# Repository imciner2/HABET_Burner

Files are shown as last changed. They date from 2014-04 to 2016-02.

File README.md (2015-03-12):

HABET_Burner
============

Burner designed for High Altitude Ballooning

Housekeeping
============
This repository makes use of git subtrees for importing its KiCad libraries. Use the following commands to work with them
* To add the remote link: git remote add libraries https://github.com/imciner2/KiCad-Libraries.git
* To pull the newest version: git subtree pull --prefix Electronics/2-Hardware/2-DesignFiles/libraries libraries master --squash
* To push the changes to the repo: git subtree push --prefix Electronics/2-Hardware/2-DesignFiles/libraries libraries master

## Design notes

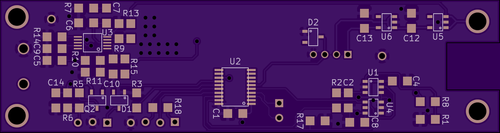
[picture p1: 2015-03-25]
Electronics/6-Documentation/Board_Bottom.png

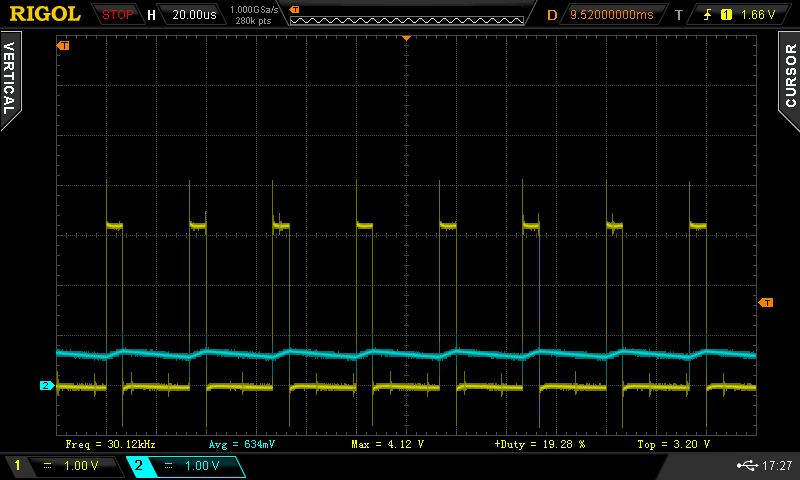
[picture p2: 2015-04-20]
Electronics/6-Documentation/PWM_Input_20Duty.png

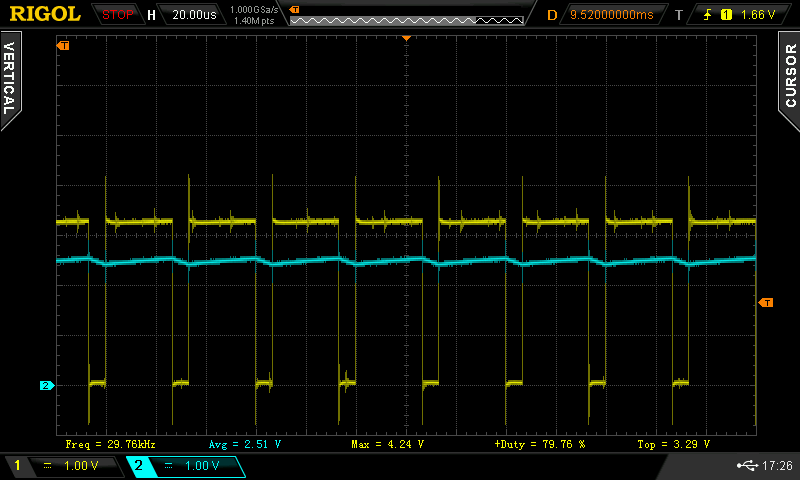
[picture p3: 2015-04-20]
Electronics/6-Documentation/PWM_Input_80Duty.png

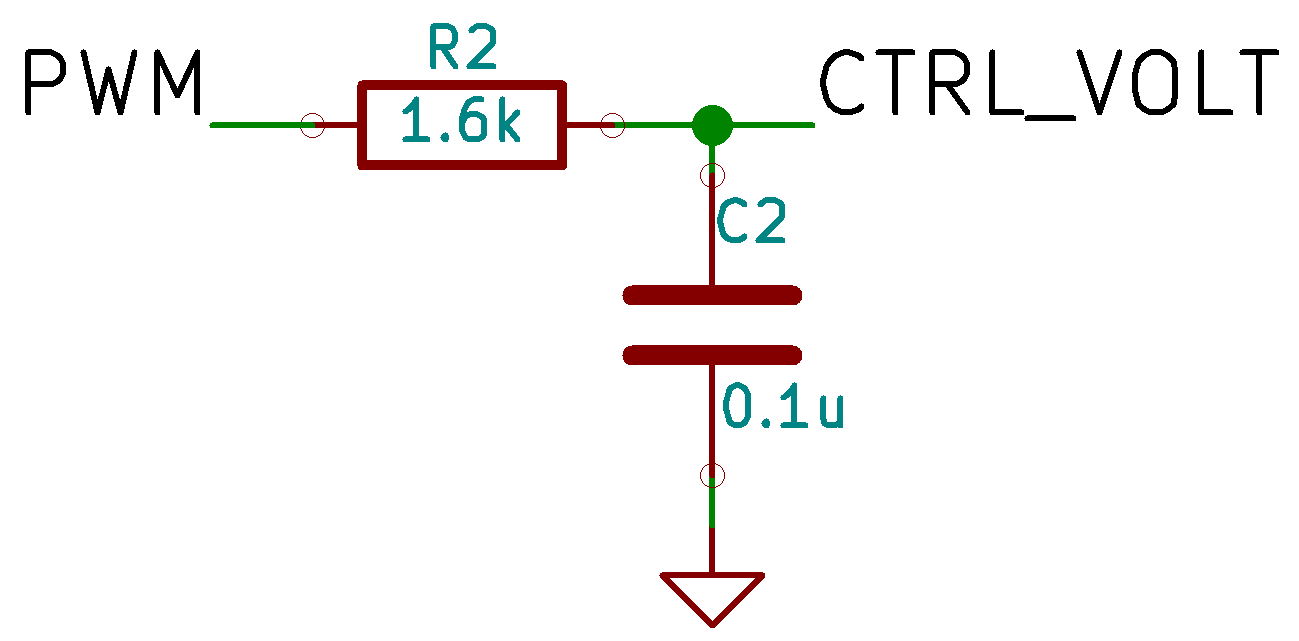
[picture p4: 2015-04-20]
Electronics/6-Documentation/Schematic-DAC_LowPassFilter.png

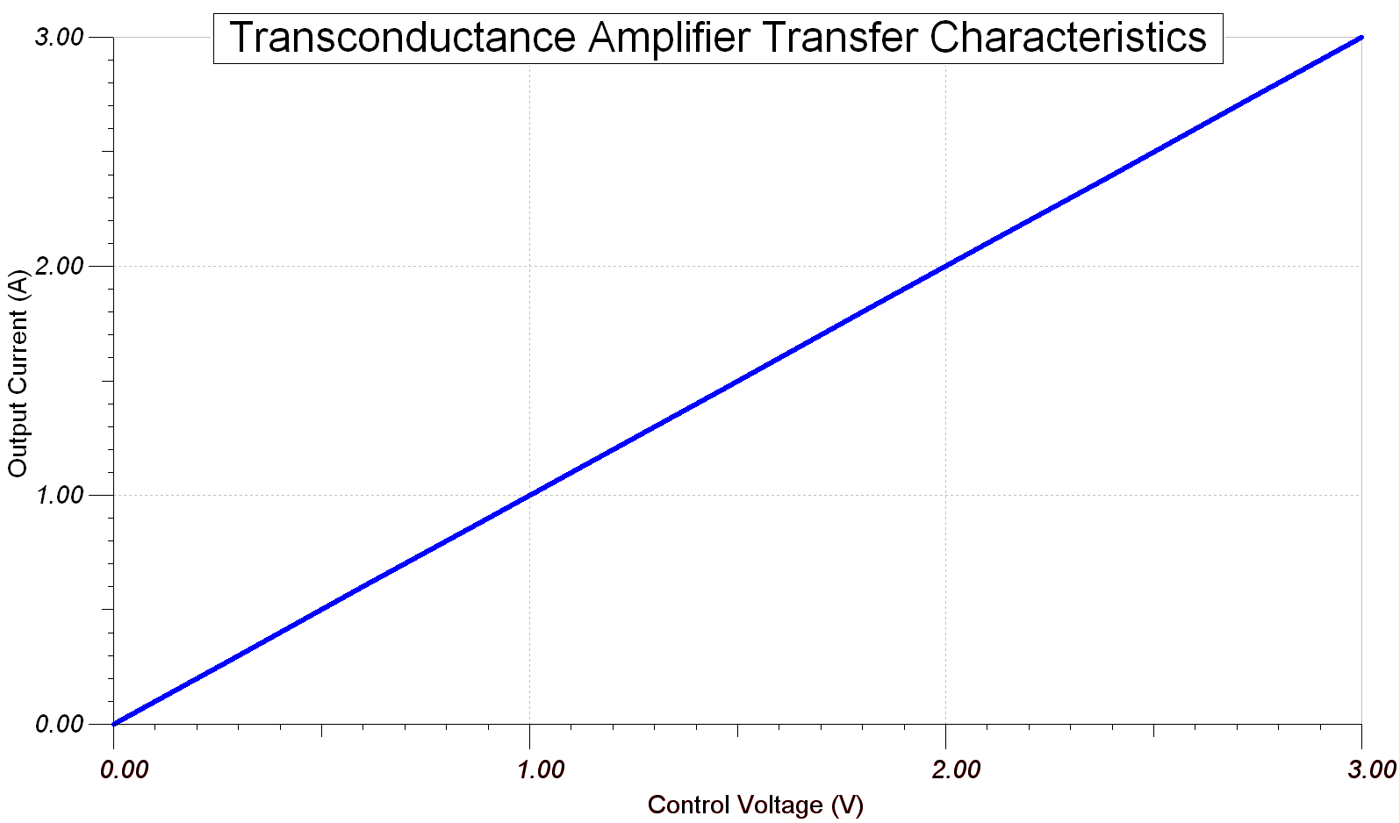
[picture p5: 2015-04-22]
Electronics/6-Documentation/Transfer-TransconductanceAmplifier.png

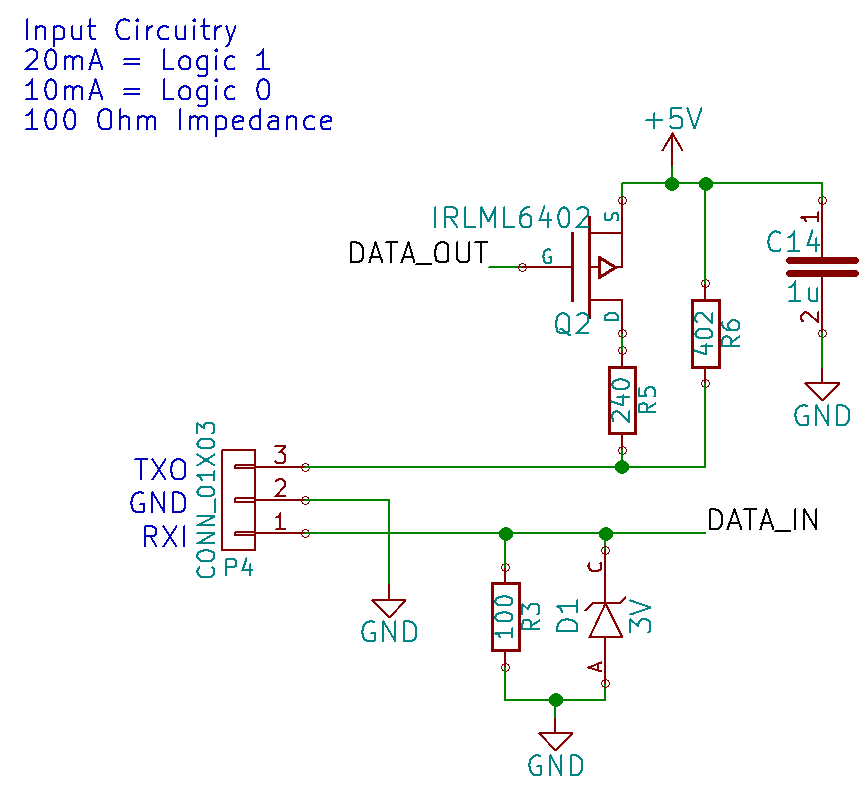
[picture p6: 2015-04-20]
Electronics/6-Documentation/Schematic-CurrentLoop.png

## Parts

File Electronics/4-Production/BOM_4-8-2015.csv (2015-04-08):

Qty | Reference(s) | Value | DigikeyNumber | Manufacturer | ManufacturerNumber
4 | C1, C2, C4, C8 | 0.1u | 311-1141-1-ND | Yageo | CC0805KRX7R8BB104
1 | C10 | 10n | 311-1136-1-ND | Yageo | CC0805KRX7R9BB103
2 | C11, C3 | 390u | P16500CT-ND | Panasonic Electronics Components | 20SVPF390M
2 | C12, C13 | 10u | 311-1355-1-ND | Yageo | CC0805ZKY5V6BB106
2 | C14, C5 | 1u | 311-1365-1-ND | Yageo | CC0805KKX7R7BB105
1 | C6 | 2.2n | 311-1129-1-ND | Yageo | CC0805KRX7R9BB222
1 | C7 | 47n | 311-1431-1-ND | Yageo | CC0805KRX7R9BB473
1 | C9 | 470n | 311-1364-1-ND | Yageo | CC0805KKX7R8BB474
2 | D1, D2 | 3V | BZX84C3V0LT1GOSCT-ND | ON Semiconductor | BZX84C3V0LT1G
1 | D3 | SL42-E3 | SL42-E3/57TGICT-ND | Vishay | SL42-E3/57T
2 | D4, D5 | D_LED | 754-1141-1-ND | Kingbright | APT3216SGC
1 | L1 | 1.8u | SRP1238A-1R8MCT-ND | Bourns | SRP1238A-1R8M
1 | Q1 | IRF9310 | IRF9310TRPBFCT-ND | International Rectifier | IRF9310TRPBF
1 | Q2 | IRLML6402 | IRLML6402PBFCT-ND | International Rectifier | IRLML6402TRPBF
1 | Q3 | IRL6342 | IRL6342TRPBFCT-ND | International Rectifier | IRL6342TRPBF
1 | Q4 | IRF6201 | IRF6201TRPBFCT-ND | International Rectifier | IRF6201TRPBF
4 | R1, R17, R18, R4 | 10k | P10.0KCCT-ND | Panasonic Electronic Components | ERJ-6ENF1002V
1 | R10 | 41.2k | P41.2KCCT-ND | Panasonic Electronic Components | ERJ-6ENF4122V
1 | R11 | 45.3k | P45.3KCCT-ND | Panasonic Electronic Components | ERJ-6ENF4532V
1 | R12 | 1 | PWR163S-25-1R00J-ND | Bournes | PWR163S-25-1R00J
1 | R13 | 8.45k | P8.45KCCT-ND | Panasonic Electronic Components | ERJ-6ENF8451V
1 | R14 | 40.2k | P40.2KCCT-ND | Panasonic Electronic Components | ERJ-6ENF4022V
2 | R15, R3 | 100 | P100CCT-ND | Panasonic Electronic Components | ERJ-6ENF1000V
1 | R16 | 3m | RHM.003ASCT-ND | Rohm Semiconductor | PMR50HZPFV3L00
1 | R19 | 110 | P110CCT-ND | Panasonic Electronic Components | ERJ-6ENF1100V
1 | R2 | 1.6k | P1.60KCCT-ND | Panasonic Electronic Components | ERJ-6ENF1601V
1 | R20 | 280 | P280CCT-ND | Panasonic Electronic Components | ERJ-6ENF2800V
1 | R5 | 240 | P240CCT-ND | Panasonic Electronic Components | ERJ-6ENF2400V
1 | R6 | 402 | P402CCT-ND | Panasonic Electronic Components | ERJ-6ENF4020V
1 | R7 | 3.16k | P3.16KCCT-ND | Panasonic Electronic Components | ERJ-6ENF3161V
2 | R8, R9 | 1k | P1.00KCCT-ND | Panasonic Electronic Components | ERJ-6ENF1001V
2 | U1, U4 | ADA4805-1 | ADA4805-1ARJZ-R7CT-ND | Analog_Devices | ADA4805-1ARJZ-R7
1 | U2 | MSP430G2553-20 | 296-28430-1-ND | Texas Instruments | MSP430G2553IPW20R
1 | U3 | LM3481 | LM3481MM/NOPBCT-ND | Texas_Instruments | LM3481MM/NOPB
1 | U5 | MIC5203-5.0 | 576-2734-1-ND | Micrel | MIC5203-5.0YM5 TR
1 | U6 | MIC5203-3.3 | 576-2728-1-ND | Micrel | MIC5203-3.3YM5 TR

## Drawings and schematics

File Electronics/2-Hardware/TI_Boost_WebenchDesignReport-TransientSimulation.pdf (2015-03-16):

## WEBENCH ® Electrical Simulation Report

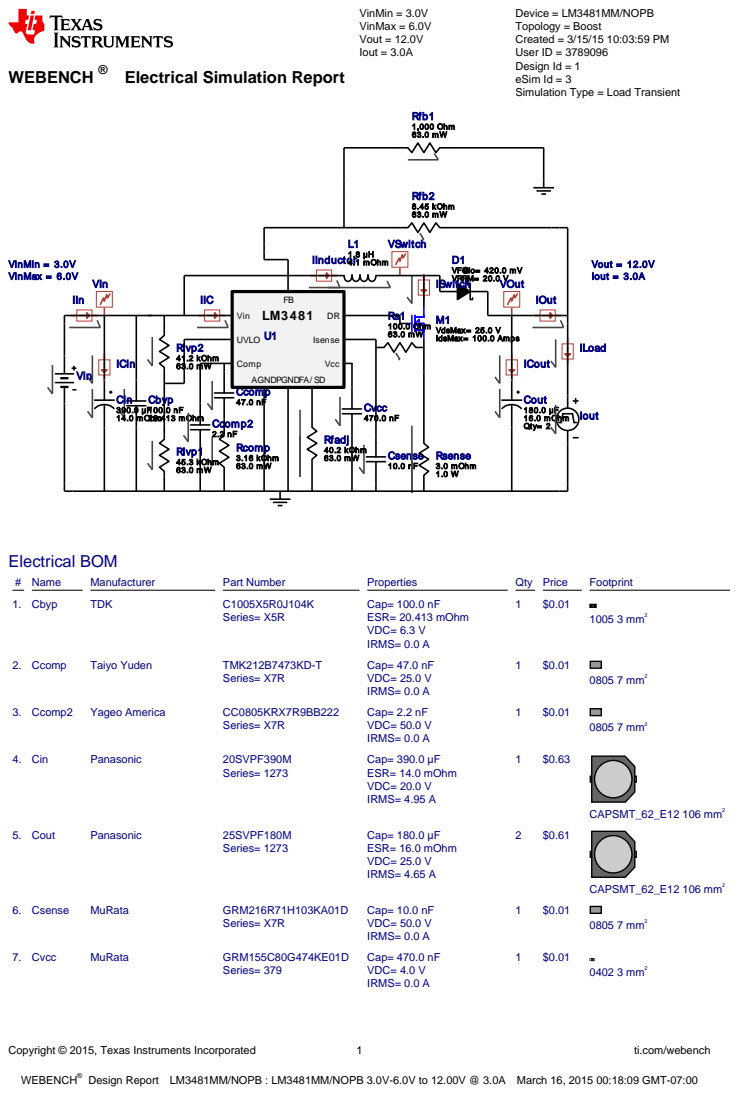
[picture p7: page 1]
Copyright © 2015, Texas Instruments Incorporated; ti.com/webench; WEBENCH®; VinMin = 3.0V VinMax = 6.0V Vout = 12.0V Iout = 3.0A; Cbyp 100.0 nF 20.413 mOhm; Ccomp 47.0 nF; Ccomp2 2.2 nF; Cin 390.0 µF; mOhm; Cout 180.0 µF 16.0 mOhm Qty= 2; Csense 10.0 nF; Cvcc 470.0 nF; D1 VF@Io= 420.0 mV VRRM= 20.0 V; ICin; ICout; IIn; IIC; IInductor; IOut; ISwitch; L1 1.8 µH 4.1 mOhm; M1 VdsMax= 25.0 V IdsMax= 100.0 Amps; Rcomp 3.16 kOhm 63.0 mW; Rfadj 40.2 kOhm 63.0 mW Rivp1 45.3 kOhm 63.0 mW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

Device = LM3481MM/NOPB
Topology = Boost
Created = 3/15/15 10:03:59 PM
User ID = 3789096
Design Id = 1
eSim Id = 3
Simulation Type = Load Transient

Design Report LM3481MM/NOPB : LM3481MM/NOPB 3.0V-6.0V to 12.00V @ 3.0A March 16, 2015 00:18:09 GMT-07:00

Design

Copyright © 2015, Texas Instruments Incorporated | 2 | ti.com/webench
# Name | Manufacturer | Part Number | Properties | Qty Price | Footprint

8. D1 | Vishay-Semiconductor | SL42-E3/57T (http://www.vishay.com/docs/88742/88742.pdf) | VF@Io= 420.0 mV VRRM= 20.0 V
1 | $0.32
| | | | | SMC 83 mm²
9. L1 | Coilcraft | XAL7070-182MEB (http://www.coilcraft.com/pdfs/xal7070.pdf) | L= 1.8 µH DCR= 4.1 mOhm
1 | $1.05

XAL7070 87 mm²
10. M1 | Texas Instruments | CSD16325Q5 (http://www.ti.com/lit/ds/symlink/csd16325q5.pdf) | VdsMax= 25.0 V IdsMax= 100.0 Amps | 1 | $0.84

TRANS_NexFET_Q5 55
mm²
11. Rcomp | Vishay-Dale | CRCW04023K16FKED (http://www.vishay.com/docs/20035/dcrcwe3.pdf) Series= CRCW..e3 | Res= 3.16 kOhm Power= 63.0 mW Tolerance= 1.0% | 1 | $0.01
0402 3 mm²
12. Rfadj | Vishay-Dale | CRCW040240K2FKED (http://www.vishay.com/docs/20035/dcrcwe3.pdf) Series= CRCW..e3 | Res= 40.2 kOhm Power= 63.0 mW Tolerance= 1.0% | 1 | $0.01
0402 3 mm²
13. Rfb1 | Vishay-Dale | CRCW04021K00FKED (http://www.vishay.com/docs/20035/dcrcwe3.pdf) Series= CRCW..e3 | Res= 1,000 Ohm Power= 63.0 mW Tolerance= 1.0% | 1 | $0.01
0402 3 mm²
14. Rfb2 | Vishay-Dale | CRCW04028K45FKED (http://www.vishay.com/docs/20035/dcrcwe3.pdf) Series= CRCW..e3 | Res= 8.45 kOhm Power= 63.0 mW Tolerance= 1.0% | 1 | $0.01
0402 3 mm²
15. Rivp1 | Vishay-Dale | CRCW040245K3FKED (http://www.vishay.com/docs/20035/dcrcwe3.pdf) Series= CRCW..e3 | Res= 45.3 kOhm Power= 63.0 mW Tolerance= 1.0% | 1 | $0.01
0402 3 mm²
16. Rivp2 | Vishay-Dale | CRCW040241K2FKED (http://www.vishay.com/docs/20035/dcrcwe3.pdf) Series= CRCW..e3 | Res= 41.2 kOhm Power= 63.0 mW Tolerance= 1.0% | 1 | $0.01
0402 3 mm²
17. Rs1 | Vishay-Dale | CRCW0402100RFKED (http://www.vishay.com/docs/20035/dcrcwe3.pdf) Series= CRCW..e3 | Res= 100.0 Ohm Power= 63.0 mW Tolerance= 1.0% | 1 | $0.01
0402 3 mm²
18. Rsense | Stackpole Electronics Inc CSNL1206FT3L00 (http://www.seielect.com/Catalog/SEI-CSNL.pdf)
| | Series= 478 | Res= 3.0 mOhm Power= 1.0 W Tolerance= 1.0% | 1 | $0.19
1206 11 mm²
19. U1 | Texas Instruments | LM3481MM/NOPB (http://www.ti.com/product/lm3481) | Switcher | 1 | $0.80

MUB10A 24 mm²

## Simulation Parameters

# Name Parameter Name | Description | Values

1. Cin | IC | Initial Condition across the capacitor | 4.5 V
2. Cout | IC | Initial Condition Across Capacitor | 12.0 V
3. Iout | signal_type | Signal Type | PULSE
I1 | Initial Current | 3.0 A
I2 | Peak Current | 0.3 A
Td | Initial Delay Time | 0.5m Sec
Tr | Rise Time | 50u Sec
Tf | Fall Time | 50u Sec
Pw | Pulse Width | 2m Sec

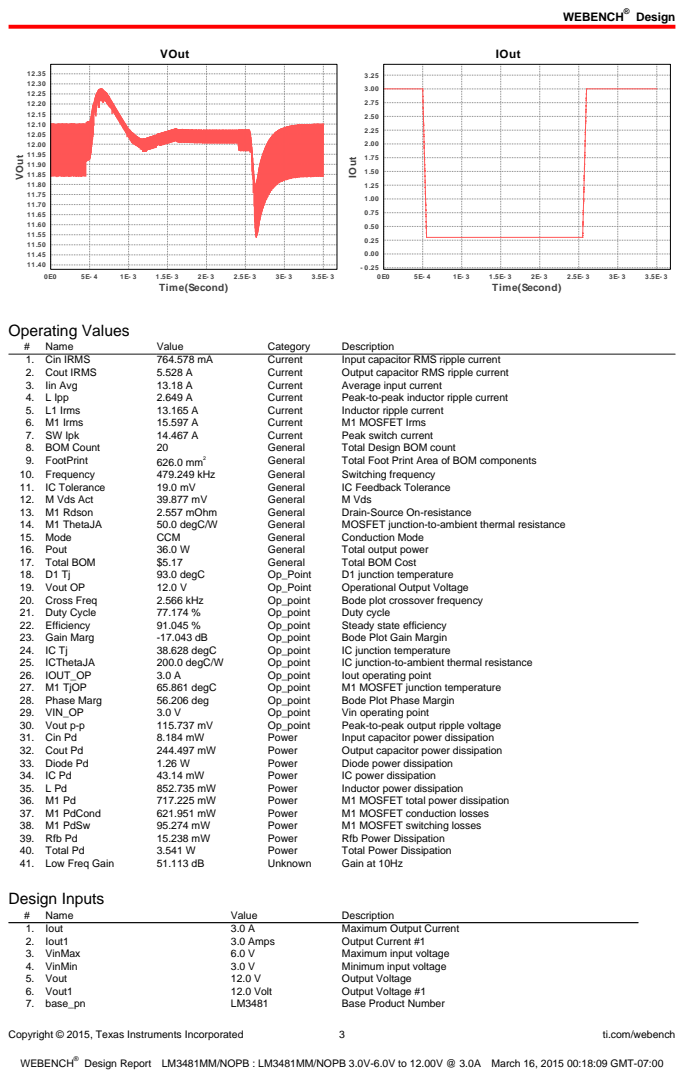
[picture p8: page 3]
Copyright © 2015, Texas Instruments Incorporated; ti.com/webench; VOut; 3.5E- 3 Time(Second); IOut; Operating Values; Name; Value; Category; Description; 1. Cin IRMS; Current; Input capacitor RMS ripple current; 2. Cout IRMS; Output capacitor RMS ripple current; 3. Iin Avg; Average input current; 4. L Ipp; Peak-to-peak inductor ripple current; 5. L1 Irms; Inductor ripple current; 6. M1 Irms; M1 MOSFET Irms; 7. SW Ipk; Peak switch current; 8. BOM Count; General; Total Design BOM count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

Copyright © 2015, Texas Instruments Incorporated | 4 | ti.com/webench
# | Name | Value | Description

8. source | DC | Input Source Type
9. Ta | 30.0 degC | Ambient temperature

## Design Assistance
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

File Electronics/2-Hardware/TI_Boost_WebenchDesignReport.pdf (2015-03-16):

## WEBENCH ® Design Report

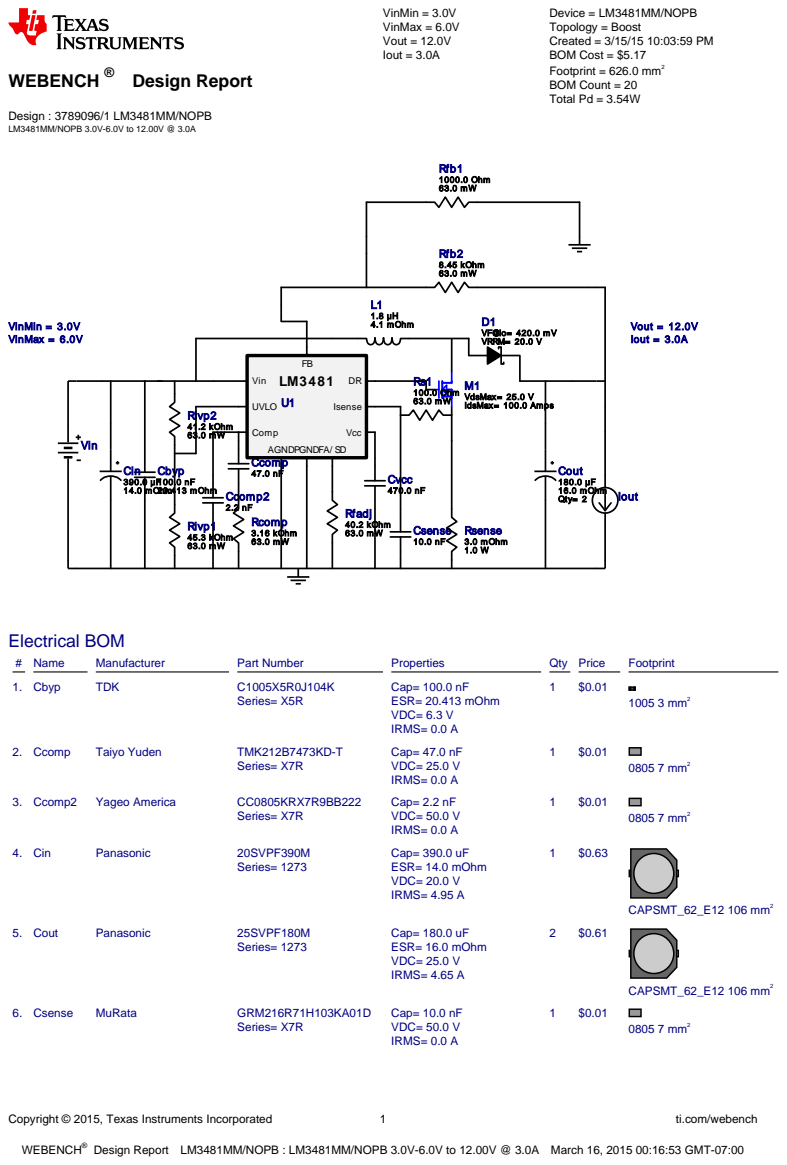
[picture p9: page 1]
Copyright © 2015, Texas Instruments Incorporated; ti.com/webench; WEBENCH®; Design : 3789096/1 LM3481MM/NOPB LM3481MM/NOPB 3.0V-6.0V to 12.00V @ 3.0A; VinMin = 3.0V VinMax = 6.0V Vout = 12.0V Iout = 3.0A; Device = LM3481MM/NOPB Topology = Boost Created = 3/15/15 10:03:59 PM BOM Cost = $5.17 Footprint = 626.0 mm² BOM Count = 20 Total Pd = 3.54W; Cbyp 100.0 nF 20.413 mOhm; Ccomp 47.0 nF; Ccomp2 2.2 nF; Cin 390.0 µF; mOhm; Cout 180.0 µF 16.0 mOhm Qty= 2; Csense 10.0 nF; Cvcc 470.0 nF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

Design Report LM3481MM/NOPB : LM3481MM/NOPB 3.0V-6.0V to 12.00V @ 3.0A March 16, 2015 00:16:53 GMT-07:00

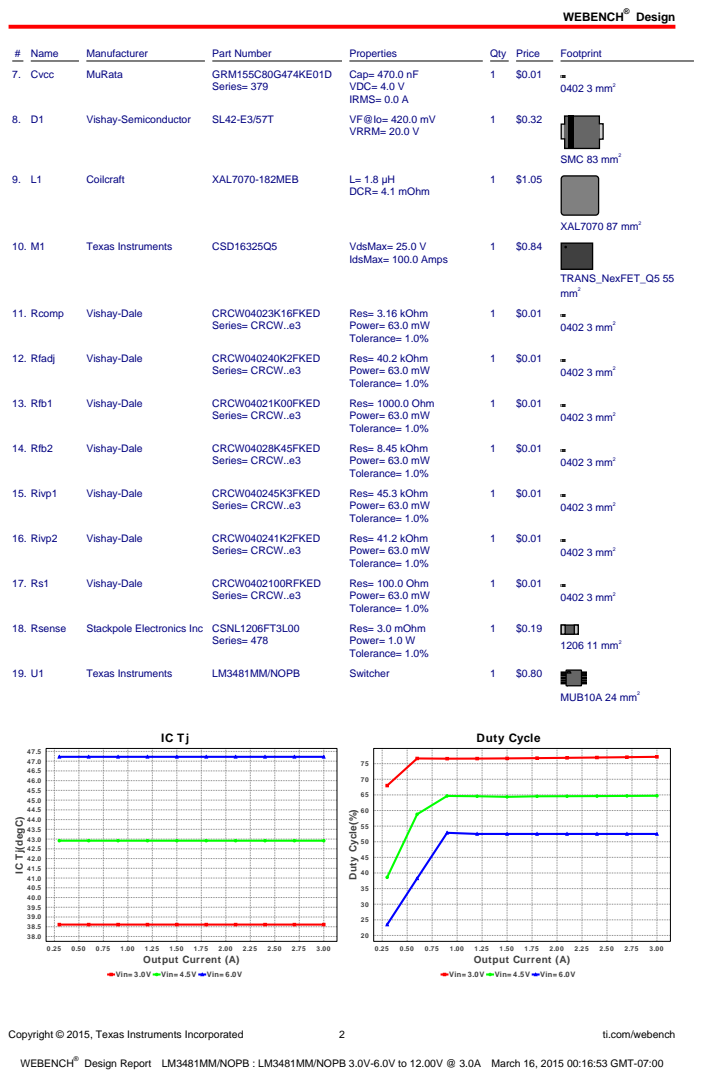
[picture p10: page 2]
Design; Copyright © 2015, Texas Instruments Incorporated; ti.com/webench; # Name; Manufacturer; Part Number; Properties; Qty Price; Footprint; 7. Cvcc; MuRata; GRM155C80G474KE01D; Series= 379; Cap= 470.0 nF VDC= 4.0 V IRMS= 0.0 A; 0402 3 mm²; Vishay-Semiconductor; VRRM= 20.0 V; SMC 83 mm²; Coilcraft; XAL7070-182MEB; DCR= 4.1 mOhm; XAL7070 87 mm²; Texas Instruments; CSD16325Q5; VdsMax= 25.0 V; IdsMax= 100.0 Amps; TRANS_NexFET_Q5 55 mm²; 11. Rcomp; Vishay-Dale; CRCW04023K16FKED; Series= CRCW..e3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

IC Tj(degC)

Vin= 3.0V Vin= 4.5V Vin= 6.0V

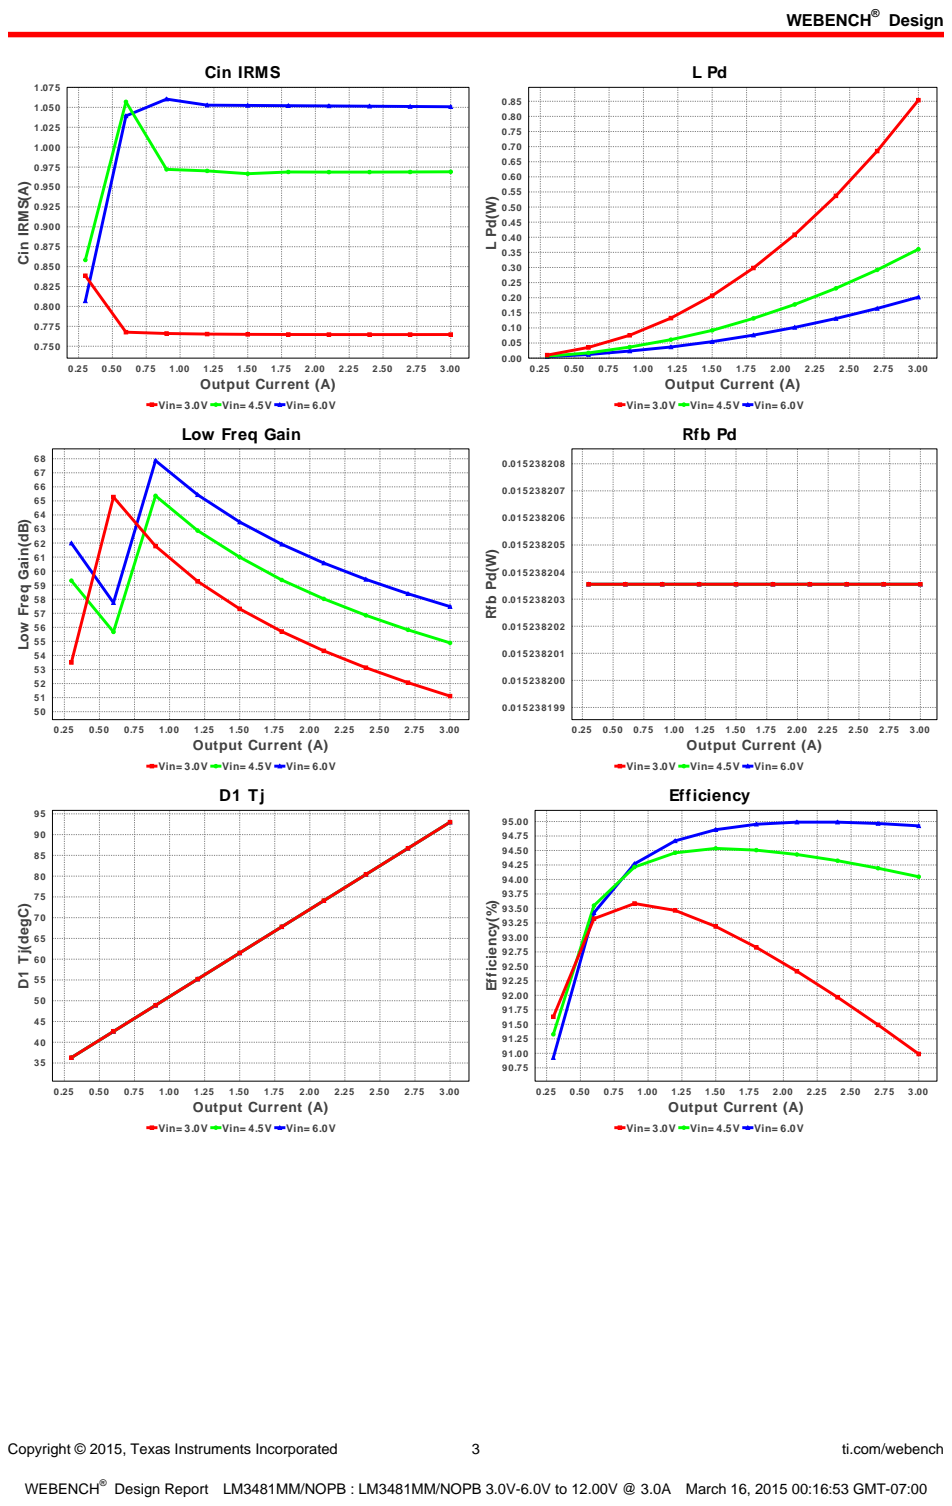
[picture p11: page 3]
Copyright © 2015, Texas Instruments Incorporated; ti.com/webench; Cin IRMS; 3.00 Output Current (A); Cin IRMS(A); 0.25 0.50 0.75 1.00 1.25 1.50 1.75 2.00 2.25 2.50 2.75 3.00 Output Current (A); Rfb Pd(W); D1 Tj(degC); Efficiency(%)

Vin= 3.0V Vin= 4.5V Vin= 6.0V
Low Freq Gain

Rfb Pd

Low Freq Gain(dB)

Efficiency

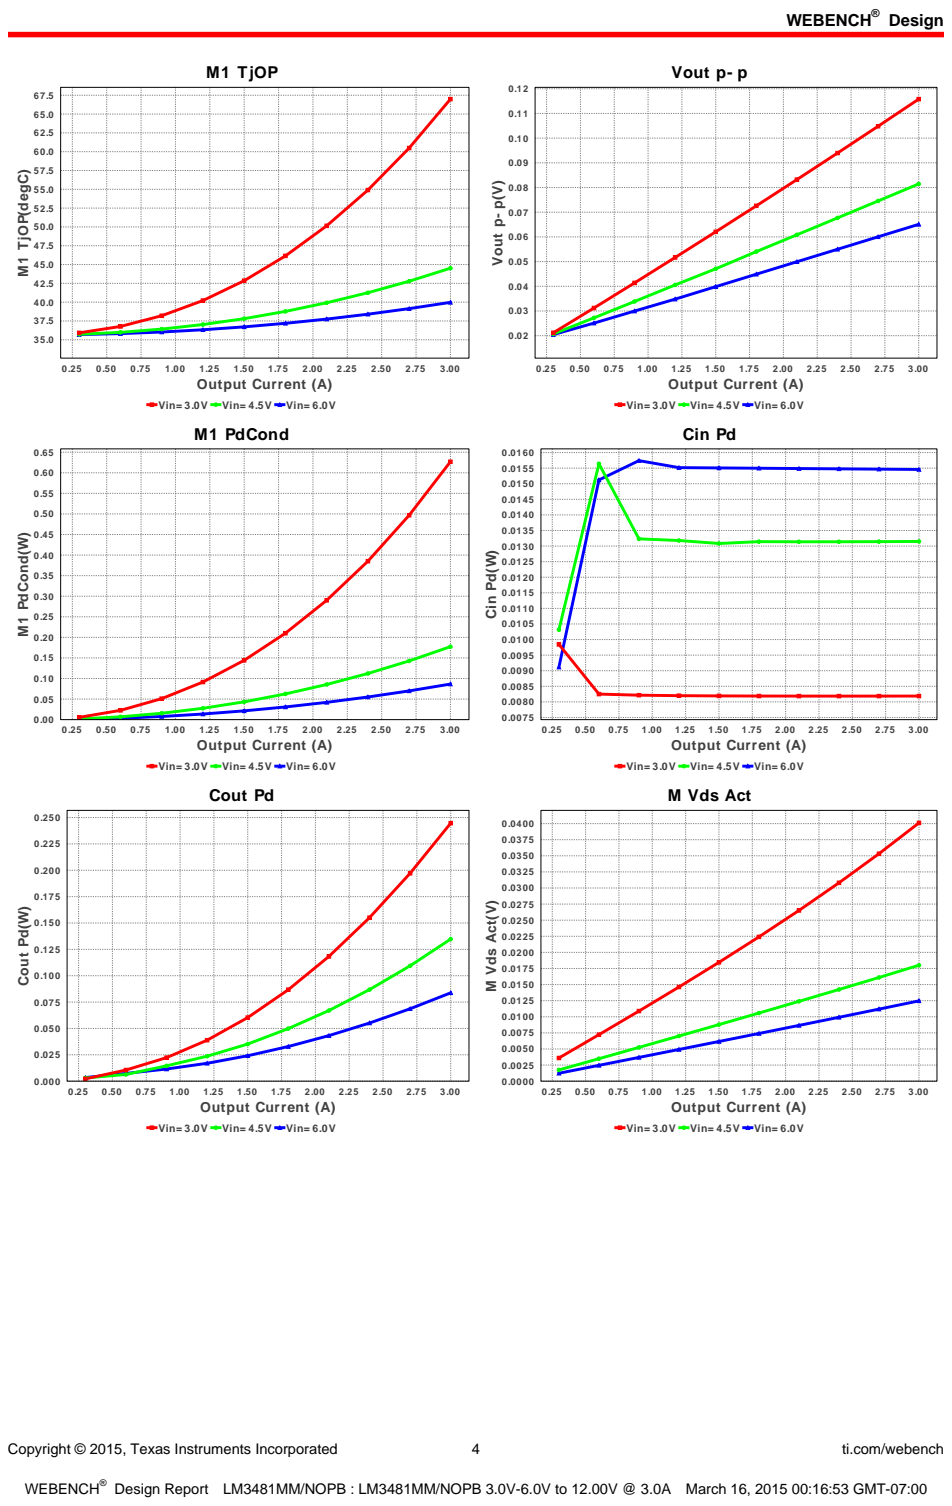
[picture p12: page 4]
Copyright © 2015, Texas Instruments Incorporated; ti.com/webench; M1 TjOP; 3.00 Output Current (A); M1 TjOP(degC); Vout p- p; Vout p- p(V); M1 PdCond(W); Cin Pd(W); Cout Pd(W); M Vds Act(V)

Vin= 3.0V Vin= 4.5V Vin= 6.0V
M1 PdCond

Cin Pd

Cout Pd

M Vds Act

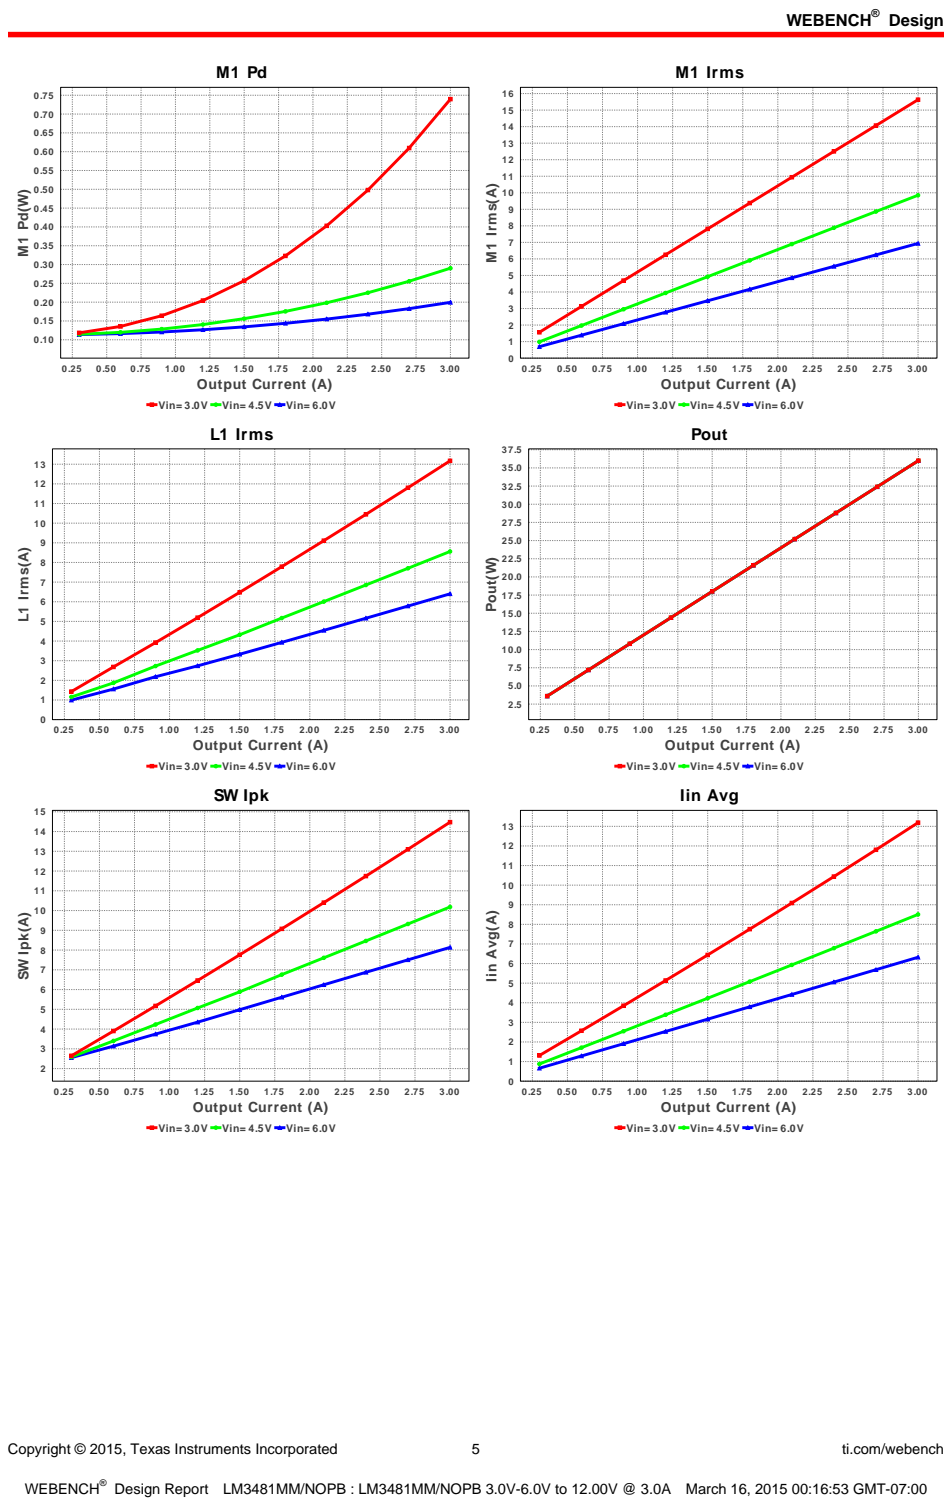
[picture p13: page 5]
Copyright © 2015, Texas Instruments Incorporated; ti.com/webench; 3.00 Output Current (A); M1 Irms; M1 Irms(A); L1 Irms(A); Pout; Pout(W); SW Ipk(A); Iin Avg(A)

Vin= 3.0V Vin= 4.5V Vin= 6.0V
L1 Irms

SW Ipk

Iin Avg

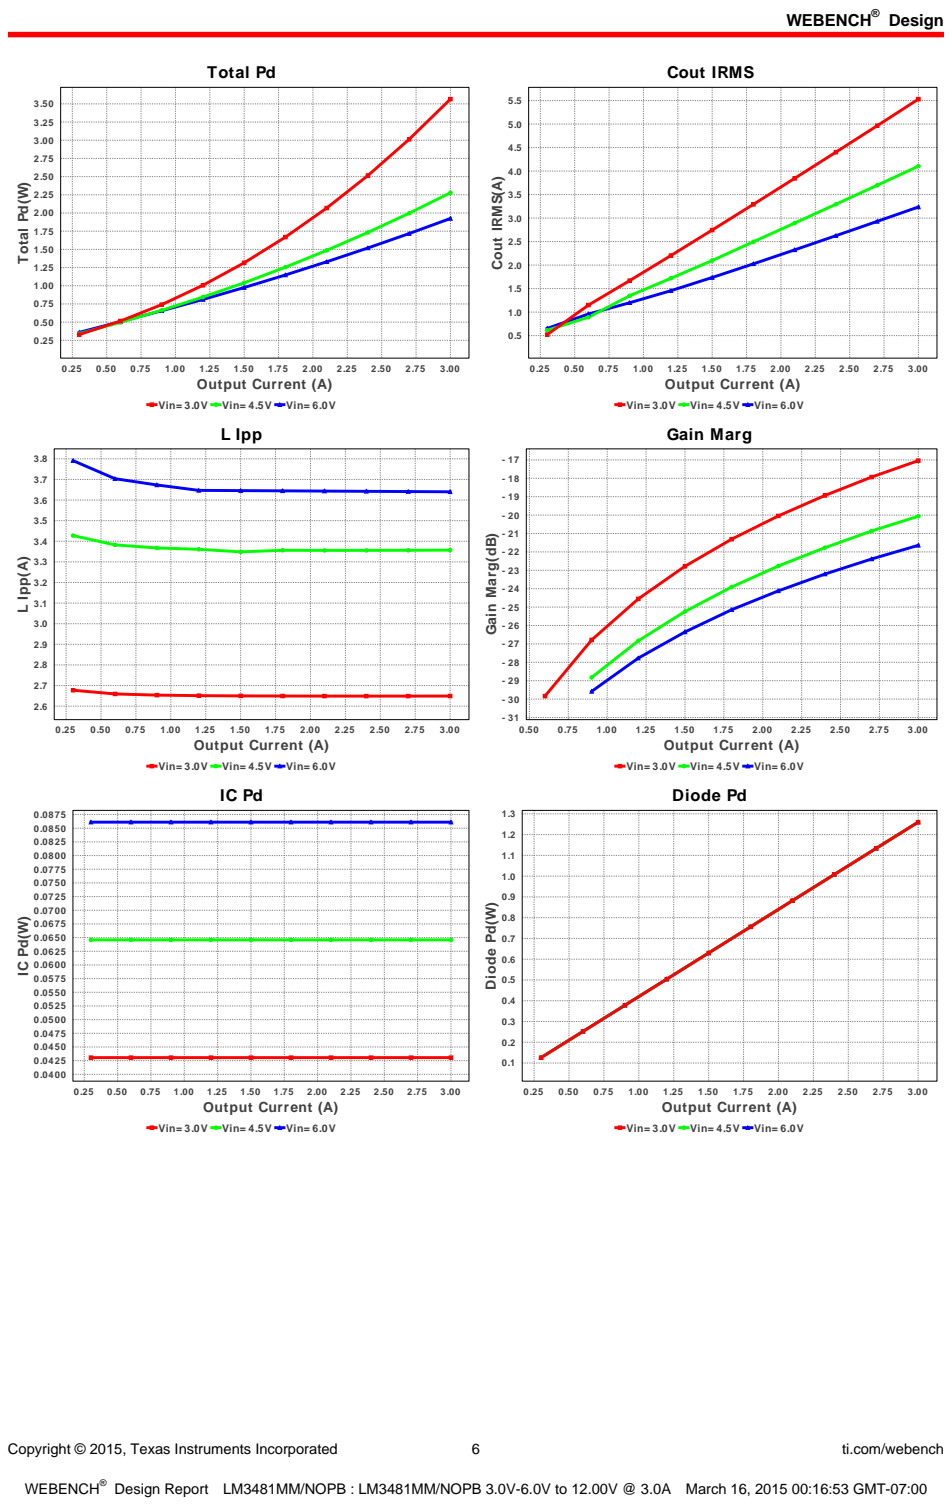
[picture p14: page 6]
Copyright © 2015, Texas Instruments Incorporated; ti.com/webench; Total Pd; 3.00 Output Current (A); Total Pd(W); Cout IRMS; Cout IRMS(A); L Ipp; L Ipp(A); Diode Pd(W)

Vin= 3.0V Vin= 4.5V Vin= 6.0V

Gain Marg

Gain Marg(dB)

Diode Pd

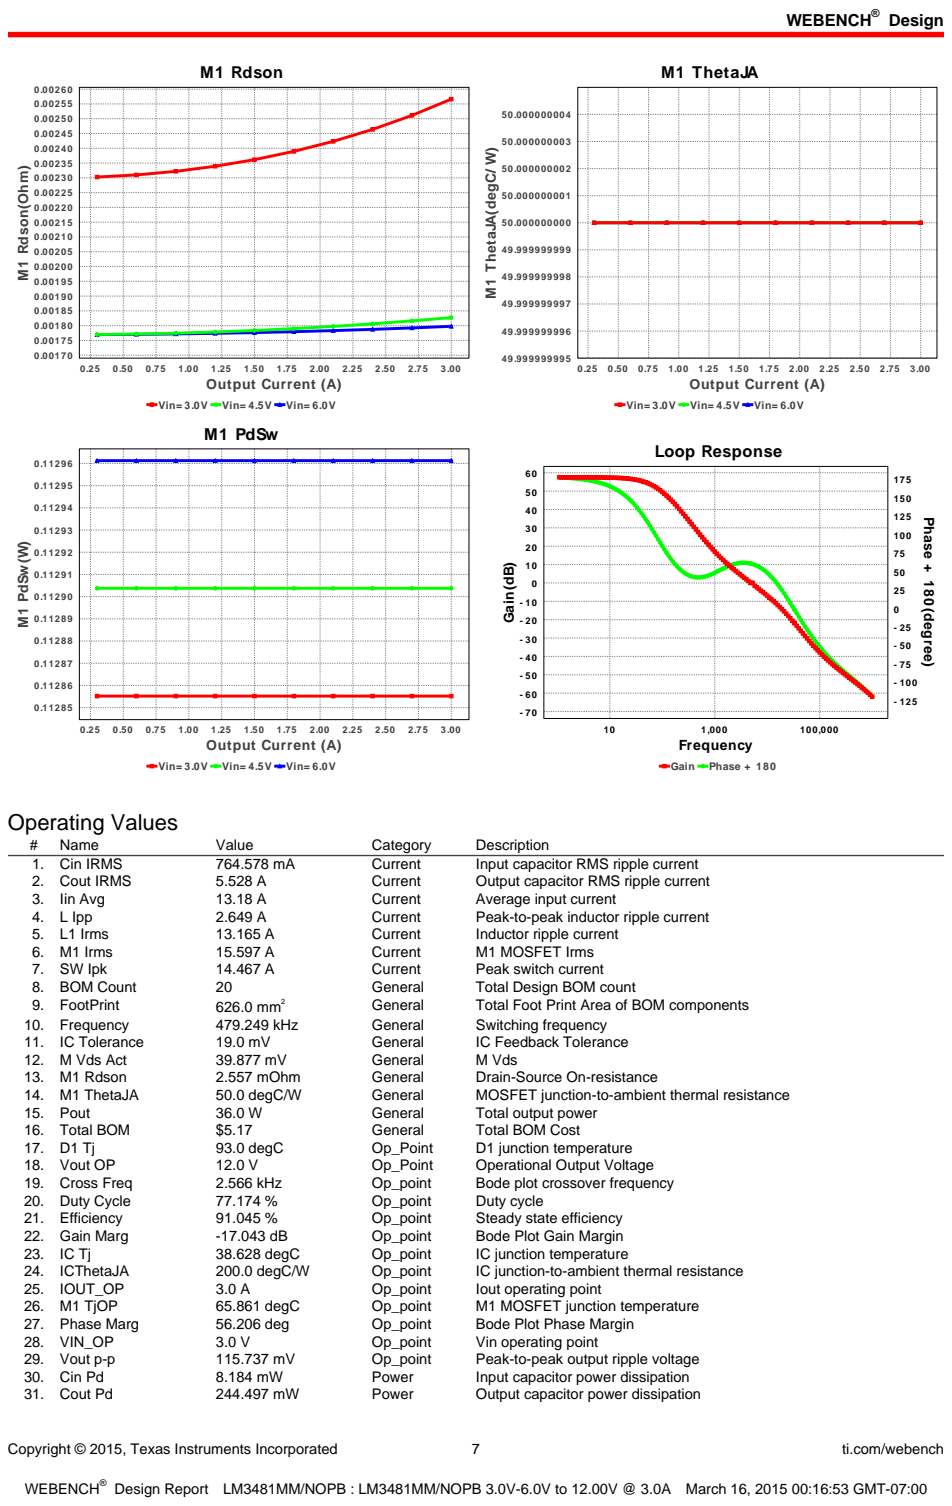
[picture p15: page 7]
Copyright © 2015, Texas Instruments Incorporated; ti.com/webench; M1 Rdson; 0.25 0.50 0.75 1.00 1.25 1.50 1.75 2.00 2.25 2.50 2.75 3.00 Output Current (A); M1 Rdson(Ohm); M1 ThetaJA; M1 ThetaJA(degC/ W); M1 PdSw(W); Loop Response; Gain Phase + 180; 100,000 Frequency; Gain(dB); Phase + 180(degree); Operating Values; Name; Value; Category; Description; 1. Cin IRMS; Current; Input capacitor RMS ripple current; 2. Cout IRMS; Output capacitor RMS ripple current; 3. Iin Avg; Average input current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

Vin= 3.0V Vin= 4.5V Vin= 6.0V
M1 PdSw

Copyright © 2015, Texas Instruments Incorporated | 8 | ti.com/webench
# | Name | Value | Category | Description

32. Diode Pd | 1.26 W | Power | Diode power dissipation
33. IC Pd | 43.14 mW | Power | IC power dissipation
34. L Pd | 852.735 mW | Power | Inductor power dissipation
35. M1 Pd | 717.225 mW | Power | M1 MOSFET total power dissipation
36. M1 PdCond | 621.951 mW | Power | M1 MOSFET conduction losses
37. M1 PdSw | 95.274 mW | Power | M1 MOSFET switching losses
38. Rfb Pd | 15.238 mW | Power | Rfb Power Dissipation
39. Total Pd | 3.541 W | Power | Total Power Dissipation
40. Low Freq Gain | 51.113 dB | Unknown | Gain at 10Hz

## Design Inputs

# | Name | Value | Description

1. Iout | 3.0 | Maximum Output Current
2. Iout1 | 3.0 | Output Current #1
3. VinMax | 6.0 | Maximum input voltage
4. VinMin | 3.0 | Minimum input voltage
5. Vout | 12.0 | Output Voltage
6. Vout1 | 12.0 | Output Voltage #1
7. base_pn | LM3481 | Base Product Number
8. source | DC | Input Source Type
9. Ta | 30.0 | Ambient temperature

## Design Assistance
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

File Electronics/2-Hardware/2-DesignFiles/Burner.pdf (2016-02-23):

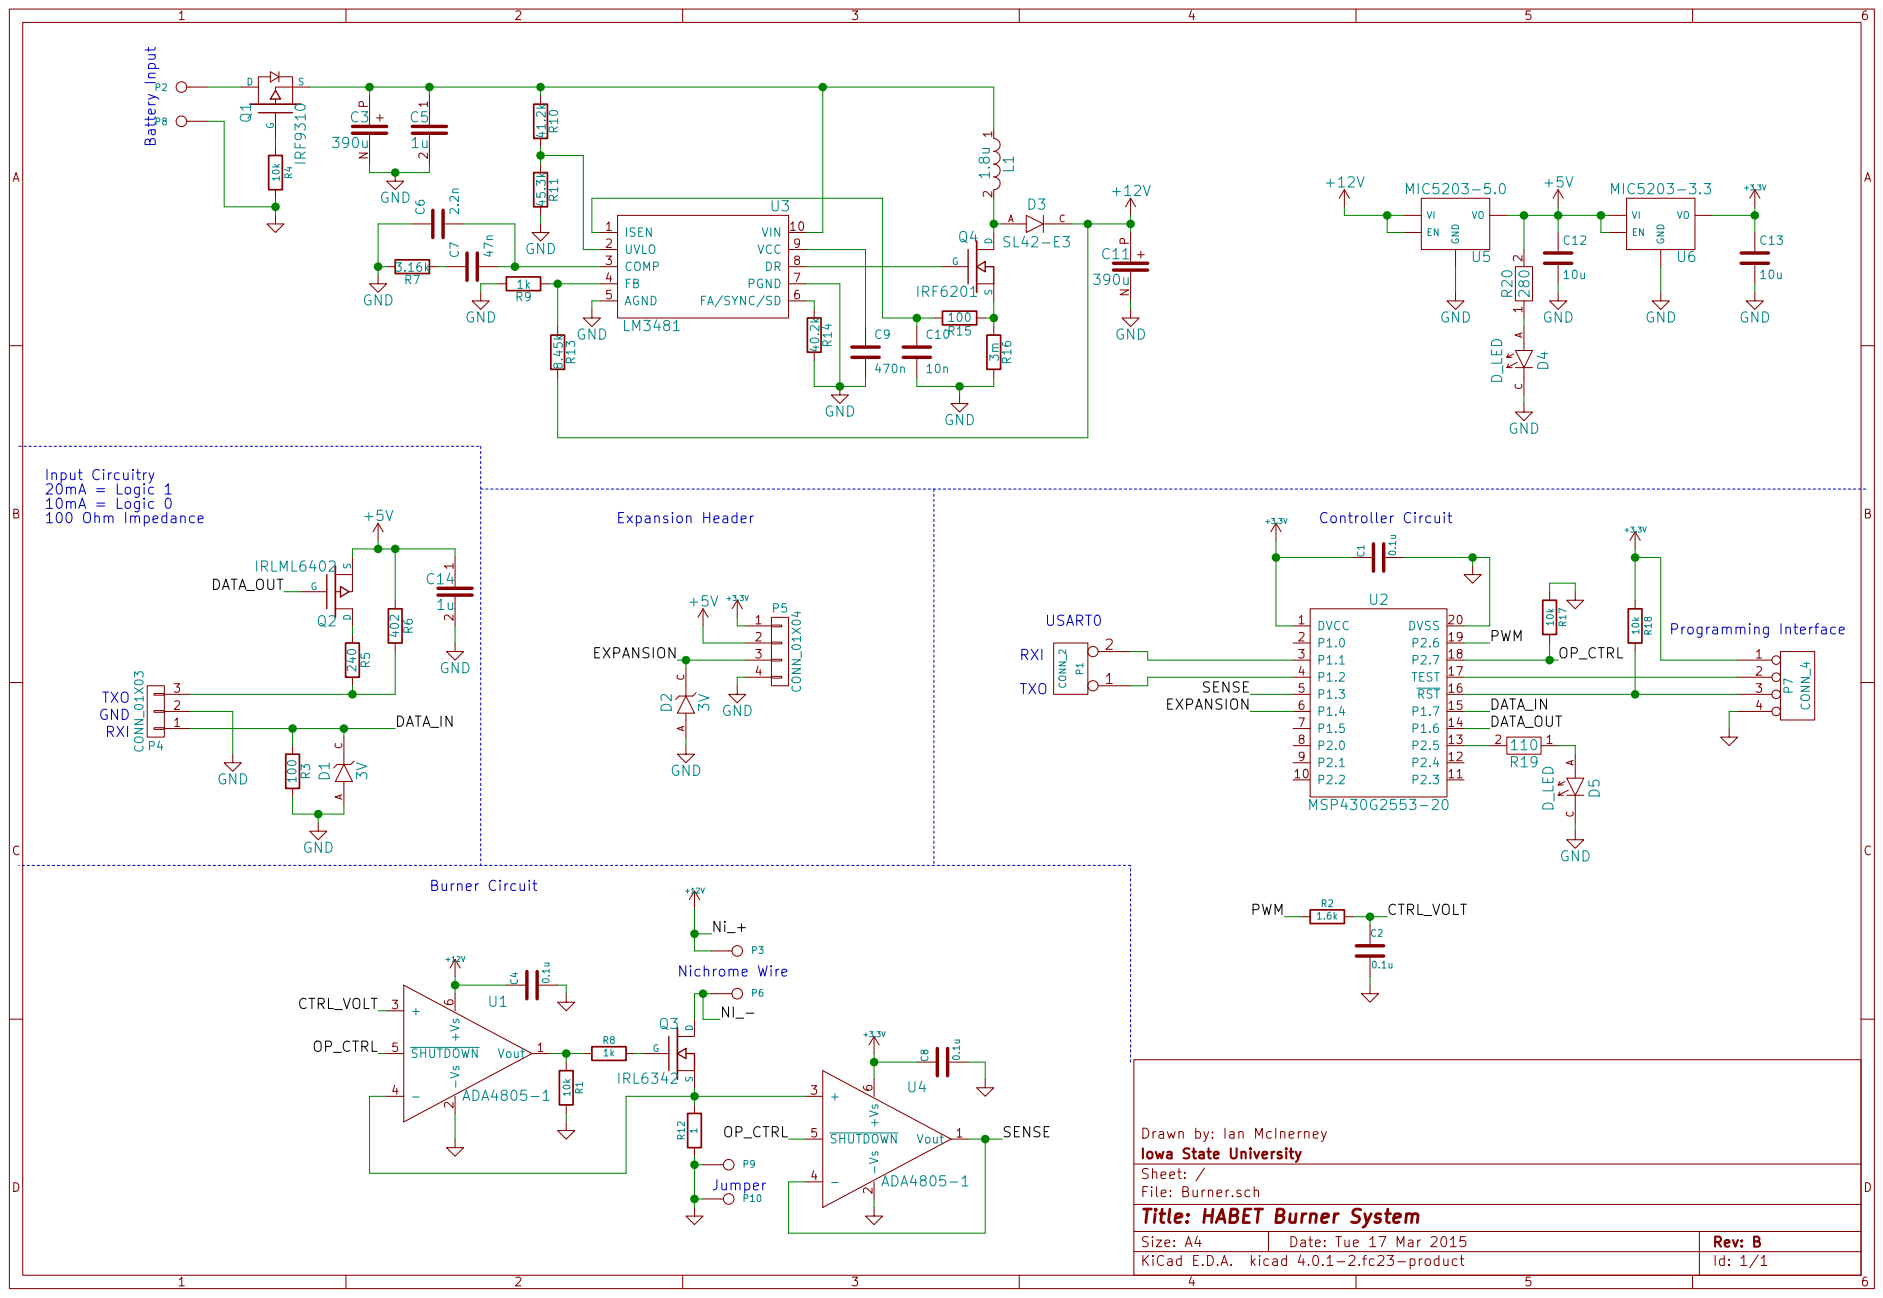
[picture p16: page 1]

Iowa State University
File: Burner.sch Sheet: /
Id: 1/1 Title: HABET Burner System

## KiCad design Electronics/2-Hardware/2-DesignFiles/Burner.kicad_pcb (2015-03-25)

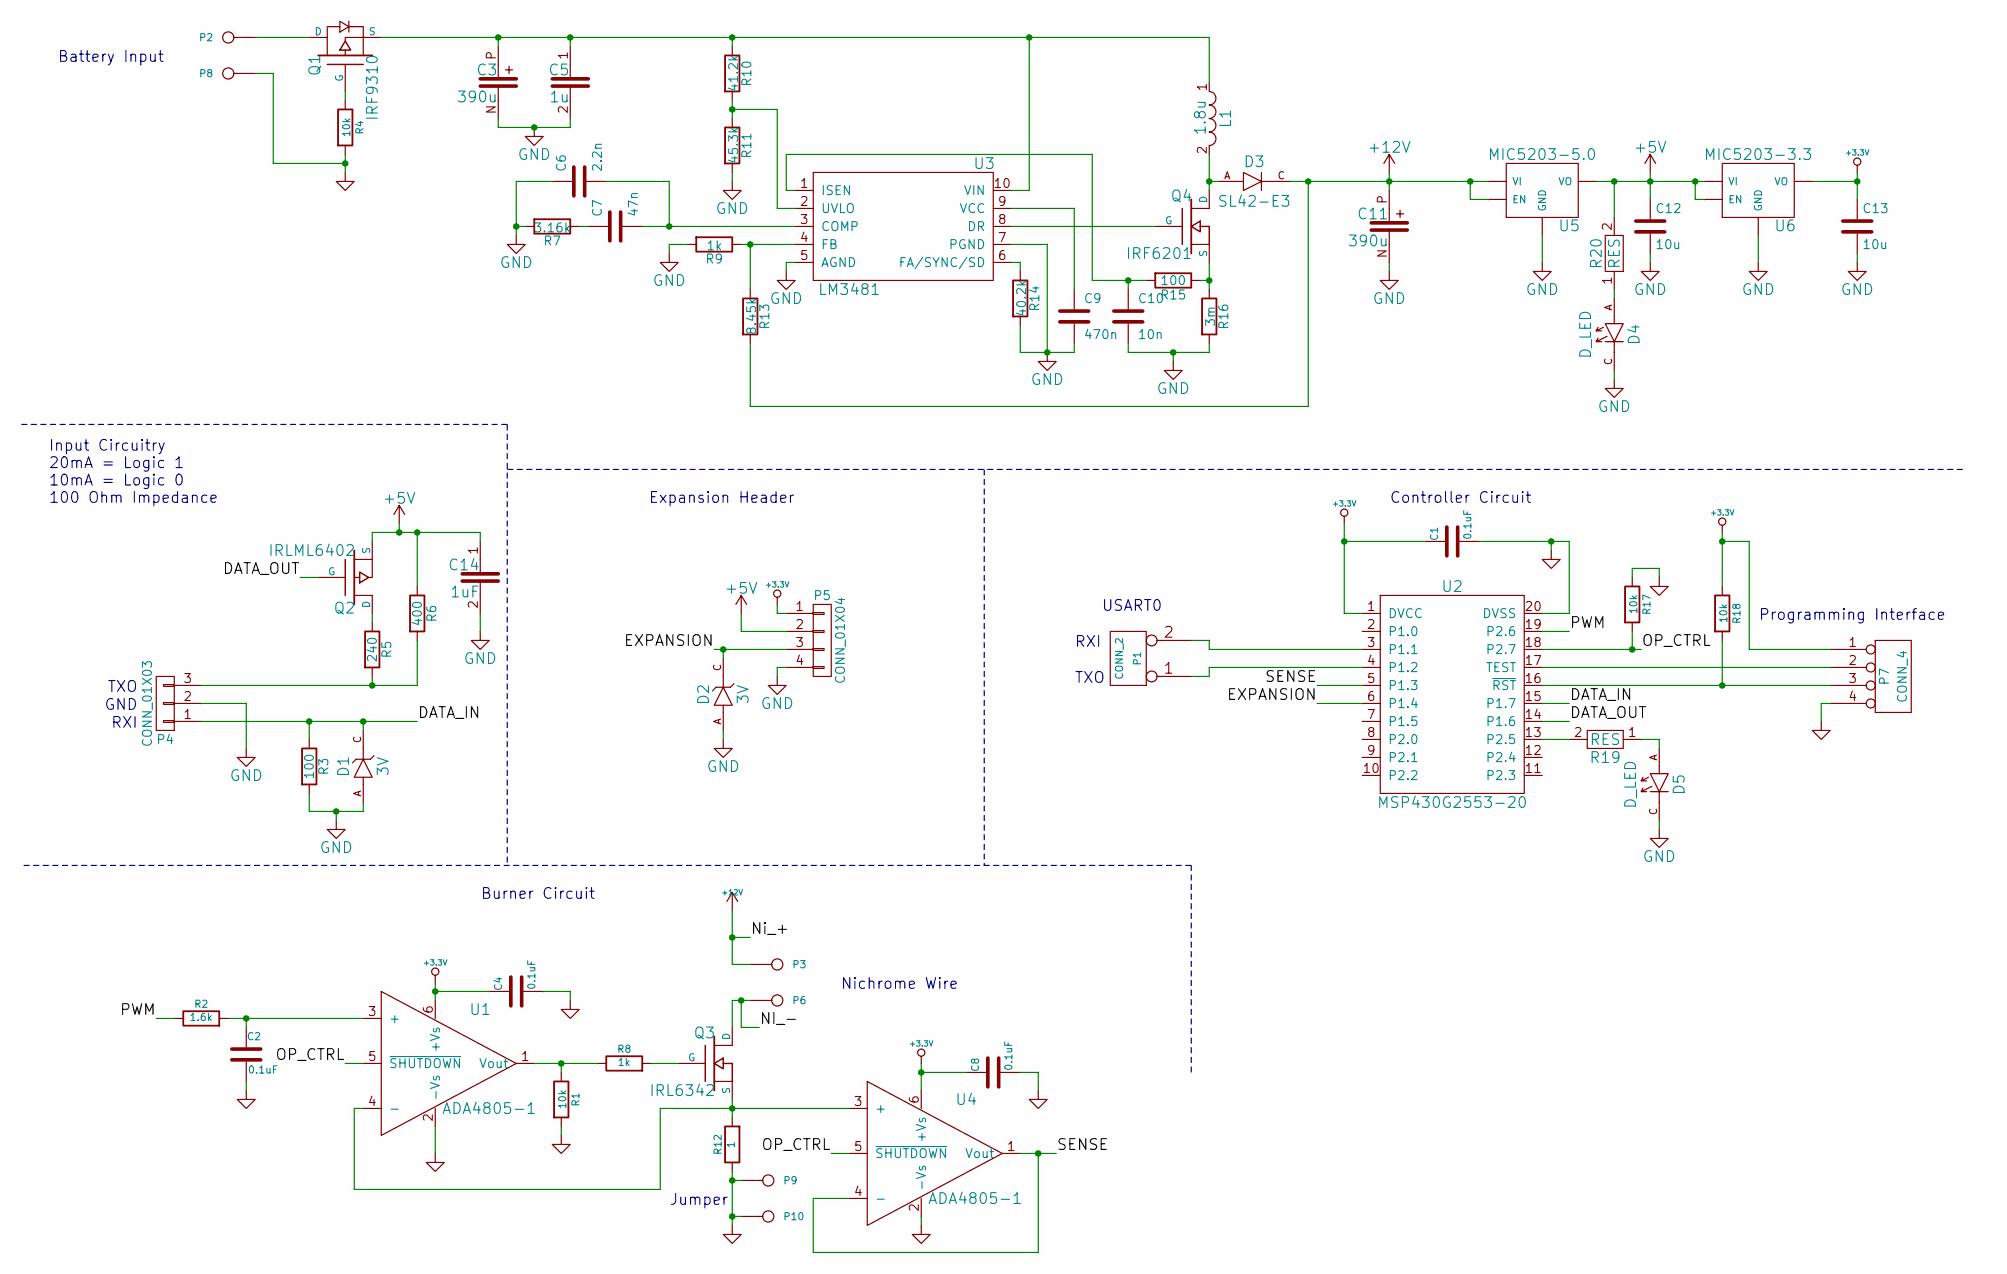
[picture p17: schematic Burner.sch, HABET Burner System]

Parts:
C1: 0.1uF; SMD_0805; DigikeyPart 311-1141-1-ND
C2, C4, C8: 0.1uF; SMD_0805
C3, C11: 390u; SMD_POL_E12_8.3mm
C5: 1u; SMD_0805
C6: 2.2n; SMD_0805
C7: 47n; SMD_0805
C9: 470n; SMD_0805
C10: 10n; SMD_0805
C12, C13: 10u; SMD_0805
C14: 1uF; SMD_0805
D1, D2: 3V; DIODE_SOT-23-3; DigikeyNumber BZX84C3V0LT1GOSCT-ND
D3: SL42-E3; DIODE_DO214AB-SMC; DigikeyNumber SL42-E3/57TGICT-ND
D4, D5: D_LED; LED_1206
L1: 1.8u; IND_BOURNS_SRP1238A; DigikeyNumber SRP1238A-1R8MCT-ND
P1: CONN_2; CONN_2.54mm_1x2
P2, P3, P6, P8, P9, P10: CONN_1; CONN_2.54mm_1x1
P4: CONN_01X03; CONN_2.54mm_1x3
P5: CONN_01X04; CONN_2.00mm_1x4
P7: CONN_4; CONN_2.54mm_1x4
Q1: IRF9310; TRANS_SO_4.0mm_1.27mm_8; DigikeyNumber IRF9310TRPBFCT-ND
Q2: IRLML6402; TRANS_SOT-23-3; DigikeyNumber IRLML6402PBFCT-ND
Q3: IRL6342; TRANS_SO_4.0mm_1.27mm_8; DigikeyNumber IRL6342TRPBFCT-ND
Q4: IRF6201; TRANS_SO_4.0mm_1.27mm_8; DigikeyNumber IRF6201TRPBFCT-ND
R1: 10k; SMD_0805; DigikeyPart P10.0KCCT-ND
R2: 1.6k; SMD_0805
R3, R15: 100; SMD_0805
R4, R17, R18: 10k; SMD_0805
R5: 240; SMD_0805
R6: 400; SMD_0805
R7: 3.16k; SMD_0805
R8, R9: 1k; SMD_0805
R10: 41.2k; SMD_0805
R11: 45.3k; SMD_0805
R12: 1; RES_D2PACK; DigikeyNumber PWR163S-25-1R00J-ND
R13: 8.45k; SMD_0805
R14: 40.2k; SMD_0805
R16: 3m; SMD_2010; DigikeyNumber RHM.003ASCT-ND
R19, R20: RES; SMD_0805
U1, U4: ADA4805-1; SOT-23-6; DigikeyNumber ADA4805-1ARJZ-R7CT-ND
U2: MSP430G2553-20; SOP_4.5mm_0.65mm_20; DigikeyPart 296-28430-1-ND
U3: LM3481; SOP_3.0mm_0.5mm_10; DigikeyNumber LM3481MM/NOPBCT-ND
U5: MIC5203-5.0; SOT-23-5; DigikeyPart 576-2734-1-ND
U6: MIC5203-3.3; SOT-23-5; DigikeyNumber 576-2728-1-ND

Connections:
+3.3V: C1.1, C4.1, C8.1, C13.1, P5.1, P7.1, R18.1, U1.6 (+Vs), U2.1 (DVCC), U4.6 (+Vs), U6.5 (VO)
+5V: C12.1, C14.1, P5.2, Q2.S, R6.1, R20.2, U5.5 (VO), U6.1 (VI), U6.3 (EN)
+12V: C11.P, D3.C, P3.1, R13.2, U5.1 (VI), U5.3 (EN)
/DATA_IN: D1.C, P4.1, R3.1, U2.15 (P1.7)
/DATA_OUT: Q2.G, U2.14 (P1.6)
/EXPANSION: D2.C, P5.3, U2.6 (P1.4)
/NI_-: P6.1, Q3.D
/OP_CTRL: R17.2, U1.5 (~SHUTDOWN), U2.18 (P2.7), U4.5 (~SHUTDOWN)
/PWM: R2.1, U2.19 (P2.6)
/SENSE: U2.5 (P1.3), U4.1 (Vout), U4.4 (-)
GND: C1.2, C2.2, C3.N, C4.2, C5.2, C6.1, C8.2, C9.2, C10.2, C11.N, C12.2, C13.2, C14.2, D1.A, D2.A, D4.C, D5.C, P4.2, P5.4, P7.4, P8.1, P9.1, P10.1, R1.2, R3.2, R4.2, R7.2, R9.2, R11.2, R12.1, R14.2, R16.2, R17.1, U1.2 (-Vs), U2.20 (DVSS), U3.5 (AGND), U3.7 (PGND), U4.2 (-Vs), U5.2 (GND), U6.2 (GND)
unnamed: C2.1, R2.2, U1.3 (+)
unnamed: C3.P, C5.1, L1.1, Q1.S, R10.1, U3.10 (VIN)
unnamed: C6.2, C7.2, U3.3 (COMP)
unnamed: C7.1, R7.1
unnamed: C9.1, U3.9 (VCC)
unnamed: C10.1, R15.2, U3.1 (ISEN)
unnamed: D3.A, L1.2, Q4.D
unnamed: D4.A, R20.1
unnamed: D5.A, R19.1
unnamed: P1.1, U2.4 (P1.2)
unnamed: P1.2 (PM), U2.3 (P1.1)
unnamed: P2.1, Q1.D
unnamed: P4.3, R5.2, R6.2
unnamed: P7.2, U2.17 (TEST)
unnamed: P7.3, R18.2, U2.16 (~RST~)
unnamed: Q1.G, R4.1
unnamed: Q2.D, R5.1
unnamed: Q3.G, R8.2
unnamed: Q3.S, R12.2, U1.4 (-), U4.3 (+)
unnamed: Q4.G, U3.8 (DR)
unnamed: Q4.S, R15.1, R16.1
unnamed: R1.1, R8.1, U1.1 (Vout)
unnamed: R10.2, R11.1, U3.2 (UVLO)
unnamed: R9.1, R13.1, U3.4 (FB)
unnamed: R14.1, U3.6 (FA/SYNC/SD)
unnamed: R19.2, U2.13 (P2.5)

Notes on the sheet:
RXI
TXO
USART0
Nichrome Wire
Burner Circuit
Controller Circuit
Programming Interface
Input Circuitry 20mA = Logic 1 10mA = Logic 0 100 Ohm Impedance
Battery Input
GND
Expansion Header
Jumper

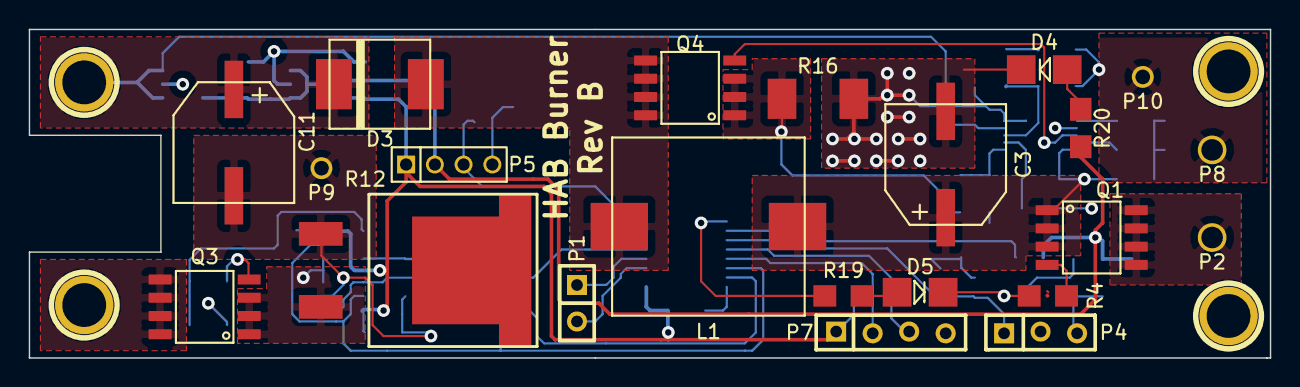
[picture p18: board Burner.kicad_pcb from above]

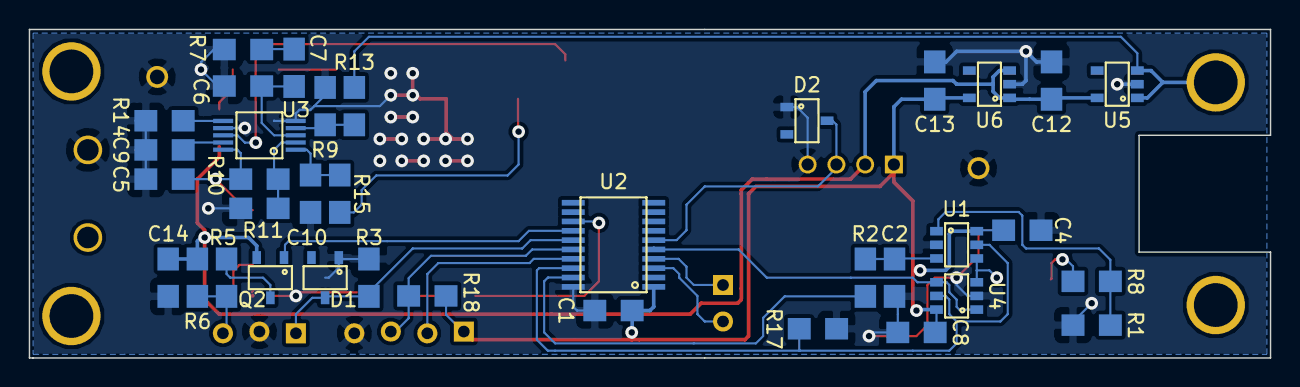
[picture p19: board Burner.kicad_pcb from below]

Board: 2 copper layers, 86.4 x 22.9 mm, 62 parts (36 on the bottom side), 37 nets.

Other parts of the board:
1PIN, 1PIN#2: P***; 1pin

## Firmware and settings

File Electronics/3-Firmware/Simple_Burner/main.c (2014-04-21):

/*
 * main.c
 */

#include <msp430.h>
#include <msp430g2553.h>
#include <stdint.h>

// The data input pin is on P2.2
#define	DATA_PIN_MASK	0x04

// The burner trigger pin is on P1.5
#define	BURNER_PIN_MASK	0x20

//#define	BURNER_PIN_MASK	0x01

// The system clock frequency
#define SYSTEM_FREQ			1000000

#define DELAY_LENGTH		1*SYSTEM_FREQ

int main(void) {
	unsigned long time = 0;

    WDTCTL = WDTPW | WDTHOLD;	// Stop watchdog timer
	
    // Set the clock to run at 1MHz
	DCOCTL = CALDCO_1MHZ;
	BCSCTL1 = CALBC1_1MHZ;

	P1OUT &= ~BURNER_PIN_MASK;		// Make sure that the pin is set for high output
	P1DIR |= BURNER_PIN_MASK;		// Set the burner's control pin to be an output
	P1SEL &= (~BURNER_PIN_MASK);	// Make sure that the pin is configured to be used for normal I/O	P1SEL2 &= (~BURNER_PIN_MASK);

	P2DIR &= (~DATA_PIN_MASK);		// Set the data input pin to be an input
	P2SEL &= (~DATA_PIN_MASK);		// Make sure that the pin is configured as normal I/O
	P2SEL2 &= (~DATA_PIN_MASK);
	P2IFG = 0x00;					// Clear the interrupt flags

	// Loop for 5 seconds (approximately) to prevent any accidental burns at power-on
	while (time != DELAY_LENGTH) {
		time++;
	}

	// Configure the input pin's interrupt
	P2IFG = 0x00;
	P2IES &= (~DATA_PIN_MASK);
	P2IE |= DATA_PIN_MASK;

	// Go into a low-power mode
	_BIS_SR(LPM4_bits + GIE);

}


// This is the ISR to handle a pin change on Port 2 pins
#pragma	vector=PORT2_VECTOR
__interrupt void Port2CN_vector( void ) {

	switch (P2IES & DATA_PIN_MASK) {
	case 0:
		// The pin is set for rising-edge interruption, so this is the start of the burn
		// Re-configure the pin for falling-edge interruption
		P2IES |= DATA_PIN_MASK;

		// Toggle the burner on (in goes high)
		P1OUT |= BURNER_PIN_MASK;


		break;
	default:
		// The pin is set for falling-edge interruption, so this is the end of the burn
		// Re-configure the pin for rising-edge interruption
		P2IES &= (~DATA_PIN_MASK);

		// Toggle the burner off (pin goes low)
		P1OUT &= (~BURNER_PIN_MASK);

		break;
	}
	P2IFG = 0;
}

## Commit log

2014-04-21 Initial commit of revision A electronics.
    [Burner.kicad_pcb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]
2015-02-18 Squashed 'Electronics/2-Hardware/libraries/' content from commit 55d656b
    git-subtree-dir: Electronics/2-Hardware/libraries
    git-subtree-split: 55d656bbbc44133183b656e17598b3c6db58abac
    [ADXL345-SCAD.stl, ADXL345-Wings.stl, ADXL345.scad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]
2015-02-18 Started new design. Fixes #1, fixes #4, fixes #6.
    [Burner.sch]
2015-02-25 Added boost convertor to schematic
    [Burner.sch]
2015-02-28 Changed DAC to be a LPF style
    [Burner.sch]
2015-03-12 Updated file structure
    [Burner.kicad_pcb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]
2015-03-12 Added MOSFETs with body diodes
2015-03-12 Updated reverse battery protection
    [Burner.sch]
2015-03-12 Updated KiCad library
2015-03-14 Added pin numbers to ADA4805, updated part fields
2015-03-14 Split out power components into their own library
2015-03-15 Update to include Kicad symbol descriptions
2015-03-15 Updated symbols on schematic
    [Burner.sch]
2015-03-15 Squashed 'Electronics/2-Hardware/2-DesignFiles/libraries/' content from commit d0926fd
    git-subtree-dir: Electronics/2-Hardware/2-DesignFiles/libraries
    git-subtree-split: d0926fdb5d0c4087c46e7bebfcc138c84b1108ec
    [ADXL345-SCAD.stl, ADXL345-Wings.stl, ADXL345.scad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]
2015-03-17 Updated MOSFETs to be NMOS and PMOS
2015-03-17 Added input circuitry, expansion port, power rails
    [Burner.sch]
2015-03-17 Footprints table for this board
2015-03-18 Created custom diode symbols
2015-03-18 Added new regulator type
2015-03-18 Started new footprints library structure
2015-03-18 Worked on component footprint matching
    [Burner.sch]
2015-03-18 Created capacitor footprint
2015-03-18 Updated footprint association for capacitors
    [Burner.sch]
2015-03-18 Updated schematic and footprint association
    [Burner.sch]
2015-03-18 Added SL42 diode footprint
2015-03-18 Added Bourns SRP1238 footprint
2015-03-18 Added diode and inductor for Boost converter
    [Burner.sch]
2015-03-23 Updated schematic with LEDs, created board layout
    [Burner.kicad_pcb, Burner.sch]
2015-03-23 Manufacturing outputs
    [Burner-B_Cu.gbl, Burner-B_Mask.gbs, Burner-Edge_Cuts.gbr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]
2015-03-23 Added new footprints libraries
2015-03-23 Updated to ignore board backup file
2015-03-23 Remove board backup file
2015-03-23 Squashed 'Electronics/2-Hardware/2-DesignFiles/libraries/' changes from 2f8a1ce..da61080
    da61080 Added Bourns SRP1238 footprint
    6299f52 Added SL42 diode footprint
    6ec2c69 Created capacitor footprint
    8325f01 Created passive symbols
    315c38a Started new footprints library structure
    71c689a Added new regulator type
    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
2015-03-23 Removed duplicate footprints
2015-03-23 Squashed 'Electronics/2-Hardware/2-DesignFiles/libraries/' changes from da61080..0f7fcab
    0f7fcab Parts for 0805, 1206, 2010 passives
    6a5b829 Instructions for 3D part creation
    b08d95c Removed duplicate footprints
    9cf71d1 Pulled the library
    511c9aa Added new footprints libraries
    git-subtree-split: 0f7fcabf2fdedd2dbf7300c4ca5b8cdbe38c048e
    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
    [SMD-0805-scad.stl, SMD-0805-wings.stl, SMD-0805.scad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]
2015-03-24 Moved parts to fix zone encroachment
    [Burner.kicad_pcb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]
2015-03-25 Fixed back silkscreen
    [Burner-B_Cu.gbl, Burner-B_Mask.gbs, Burner-B_SilkS.gbo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]
2015-03-25 Moved some references on the bottom
    [Burner-B_Cu.gbl, Burner-B_Mask.gbs, Burner-B_SilkS.gbo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]
2015-03-25 Changed drill file to have zeros
    [Burner.drl]
2015-03-25 Board pictures from OSHpark
2015-04-08 Updated component part numbers
    [Burner.sch]
2015-04-08 Final circuit information for Rev B
    [BOM_4-8-2015.csv, BOM_4-8-2015.xls]
2015-04-20 Changed transconductance op-amp power supply. Reorganized schematic
    [Burner.sch]
2015-04-20 Added pictures of specific parts of the circuit.
2015-04-20 Added pictures of specific parts of the circuit
2016-02-23 Updated PDF Schematic
